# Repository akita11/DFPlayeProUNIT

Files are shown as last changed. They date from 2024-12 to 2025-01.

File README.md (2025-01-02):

# DFPlayerProUNIT

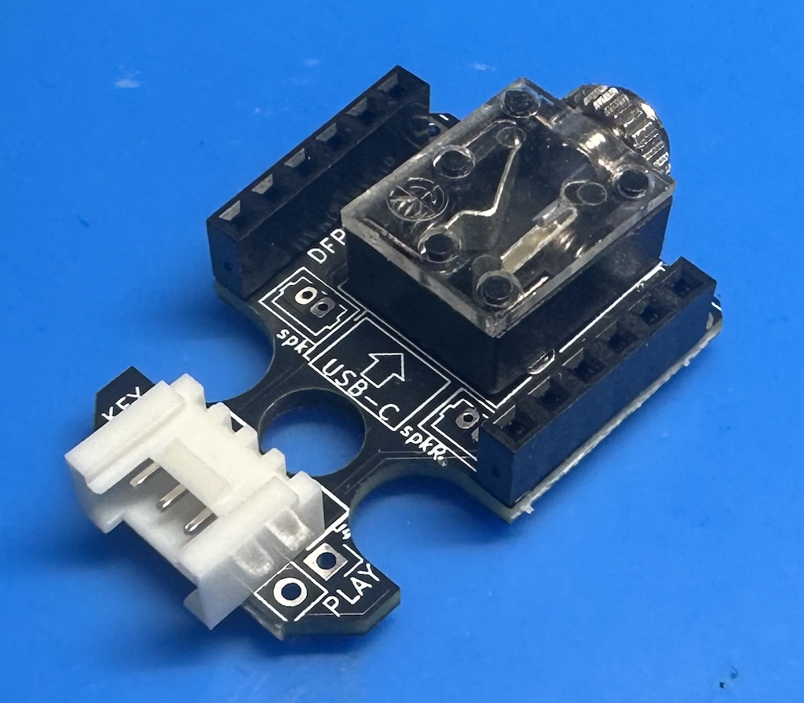
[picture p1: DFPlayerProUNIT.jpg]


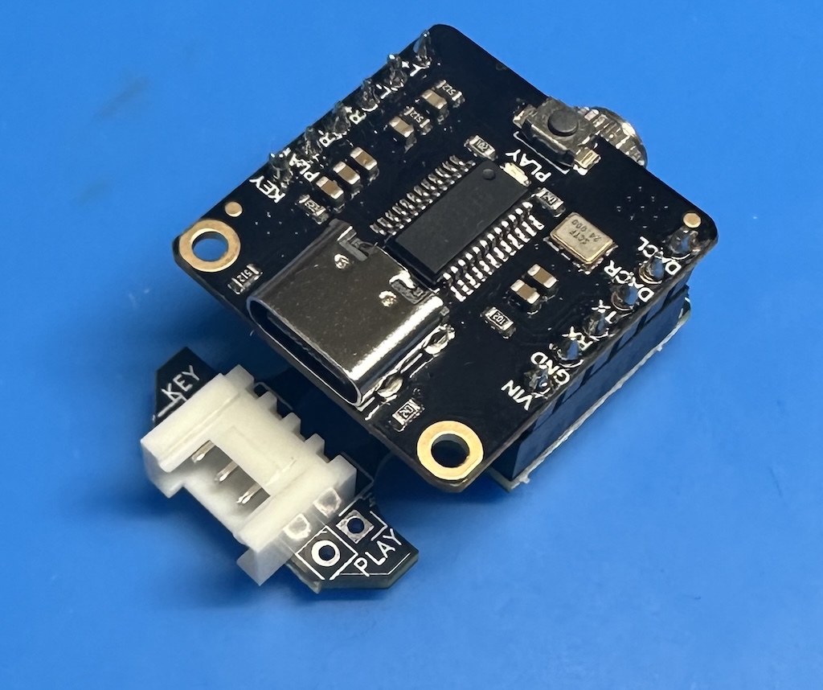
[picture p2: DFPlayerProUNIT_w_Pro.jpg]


DFRobotの音声プレーヤモジュール[DFPlayer Pro](https://www.switch-science.com/products/8005)をGrove端子を接続して制御できるモジュールです。Grove端子からシリアル(UART)通信で音声再生などを制御することができます。（UIFlow(v1)用のブロックも用意する予定）

※DFPlayerProは付属していません

## 使い方（接続方法）

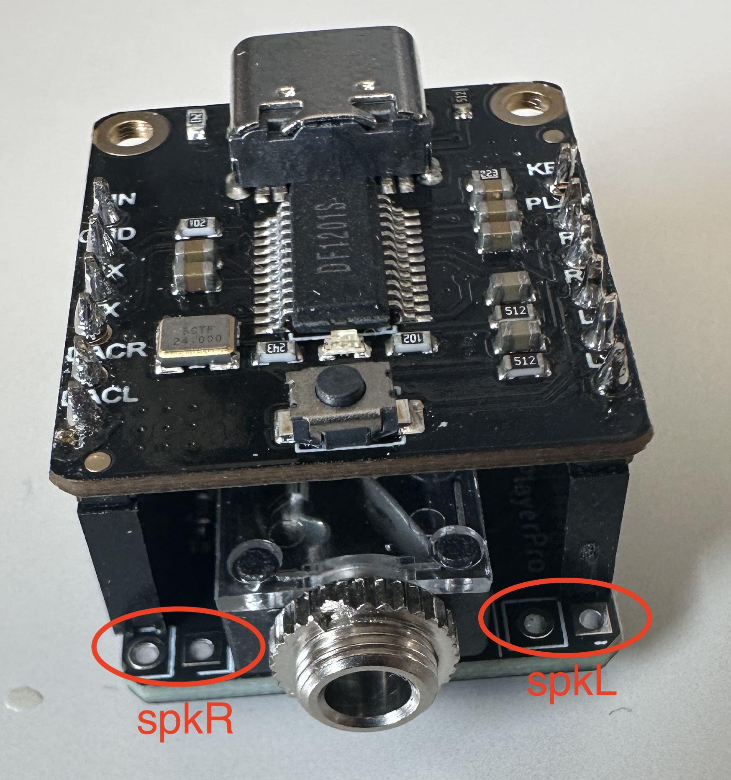
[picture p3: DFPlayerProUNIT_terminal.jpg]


以下のようにスピーカやアンプを接続し、Grove端子からの制御で音声を再生します。また基板上の"PAYE"と"KEY"のシルクが示されている2組の端子は、それぞれDFPlayerProのKEY、PLAY端子に接続されていますので、これらを使って再生を制御することもできます（詳細はDFPlayerProのマニュアルを参照してください）

### アンプ付きスピーカに接続する場合

3.5mmジャック（ステレオ：上部中央）に3.5mmステレオケーブル等でアンプに接続します。

### スピーカを直接接続する場合

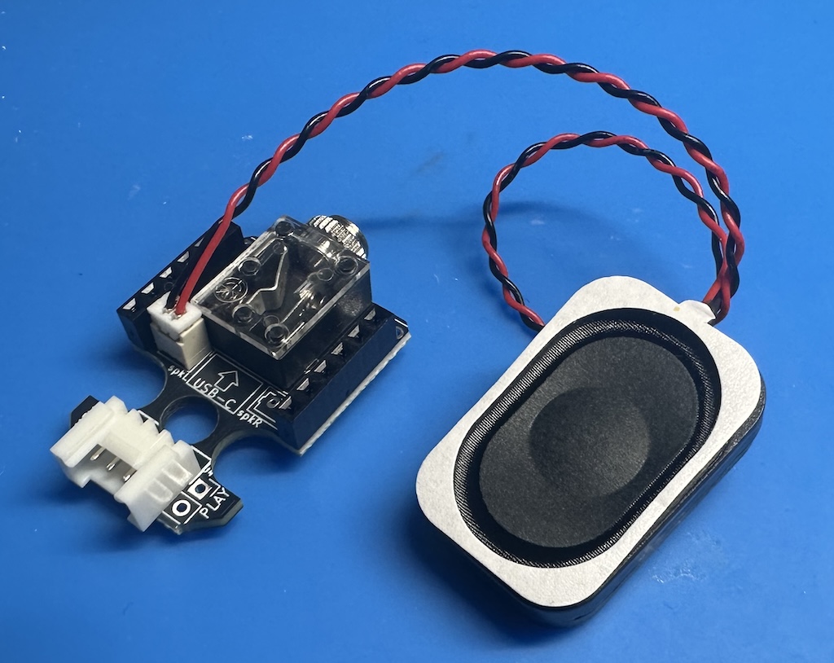
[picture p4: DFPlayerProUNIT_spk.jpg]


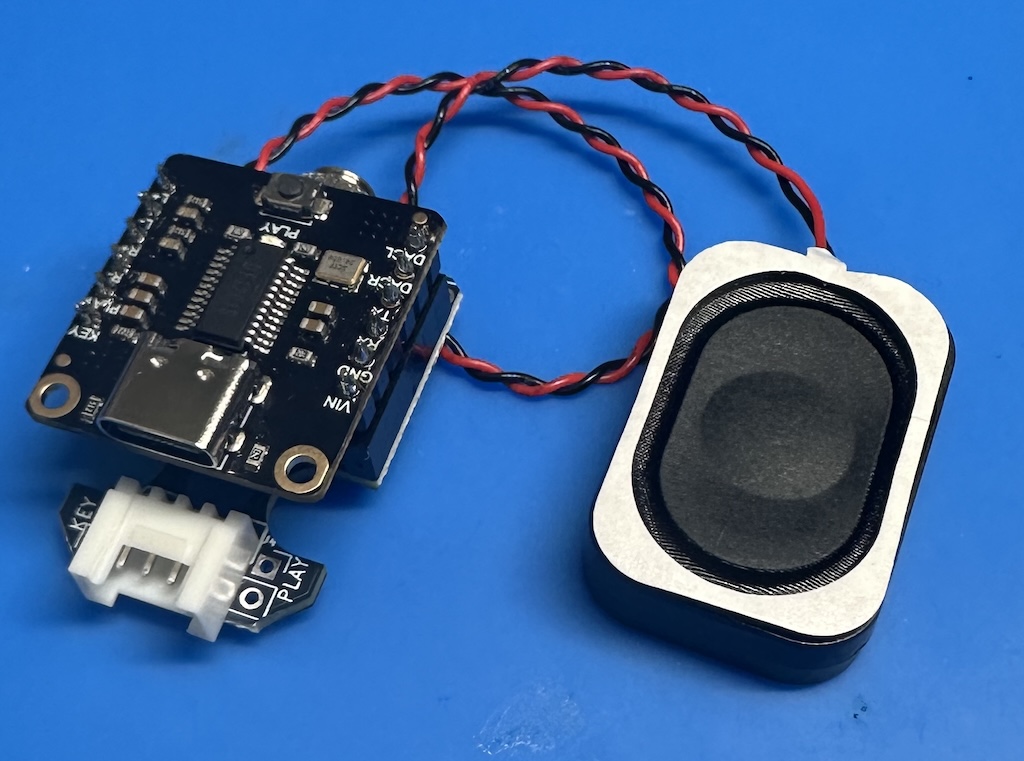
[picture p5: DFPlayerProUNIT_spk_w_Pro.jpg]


本体上部の2つの2.54mmた端子にスピーカを接続します。spkLとspkRがそれぞれお左と右のスピーカです。基板中央部に1.25mmピッチコネクタ(Molex 53047-0210用)をとりつける端子があり、市販の小型スピーカ（M5Stack本体に使われているものなど。AliExpressやTaobaoでも同等品があります）を接続することができます。

### 3.5mmジャックに直接スピーカを接続する方法

3.5mmジャックに直接スピーカを接続することもできます。その場合は、基板裏面のハンダジャンパを以下のように修正してください。

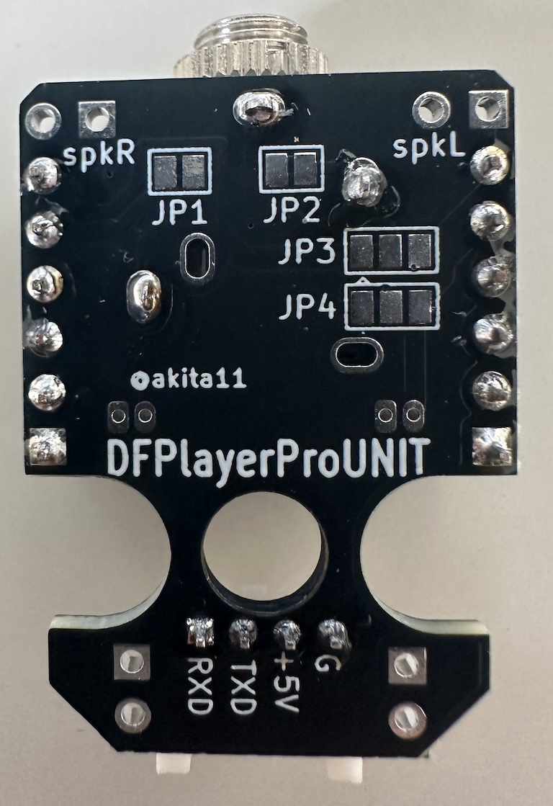
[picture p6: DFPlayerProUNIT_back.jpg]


- JP1をカット
- JP2・JP3の中央と△マーク側をカットし、中央と反対側（△マークがない側）をショート

## 使い方（ソフトウエア）

あらかじめ、DFPlayerProをUSB Type-Cケーブルを使ってPCへ接続し、現れるドライブに使用する音声データ（*.mp3等）をコピーしておきます。（このときコピーした順番が、再生時に使用する「曲番号」になります）

### UIFlow(v1)での使い方

「DFPlayerPro.m5b」をダウンロードし、UIFlow(v1)の"Custom"の"Open *.m5b"からこのファイルを指定すると、Init、Play、Volumeの3つのブロックを使用できます。

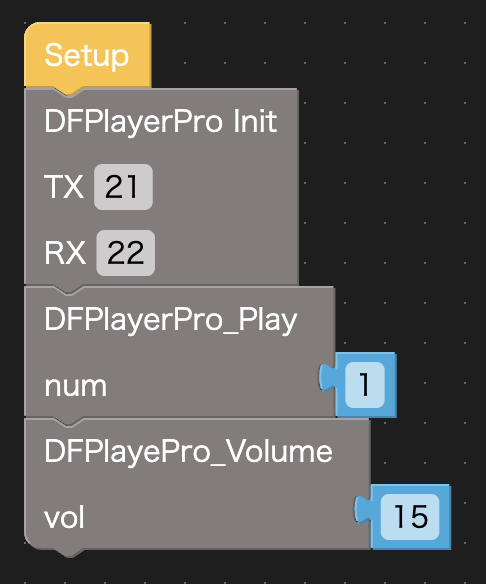
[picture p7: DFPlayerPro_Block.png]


- DFPlayerPro_Init : 初期化。最初に1回だけ読み出します。"TX"と"RX"には、使用するGroveポート・マイコン本体にあわせて、使用するピン番号を指定します。例えば、M5StackBasicのPortA（本体の赤いコネクタ）の場合は、上図のようにTX=21、RX=22を指定します。M5StackCore2のPortAの場合は、TX=32、RX=33となります。
- DFPlayerPro_Play : numに指定した「曲番号」の音声を再生します。
- DFPlayerPro_Volume : volに指定した音量に設定します。

### その他のソフトウエアでの使い方

Arduino用にはライブラリがあるようなので、そちらを使ってもOKです。
あるいは、DFPlayerProのデータシート等を参考に、制御コマンドを送信して使用してください。

## Author

Junichi Akita (@akita11) / akita@ifdl.jp

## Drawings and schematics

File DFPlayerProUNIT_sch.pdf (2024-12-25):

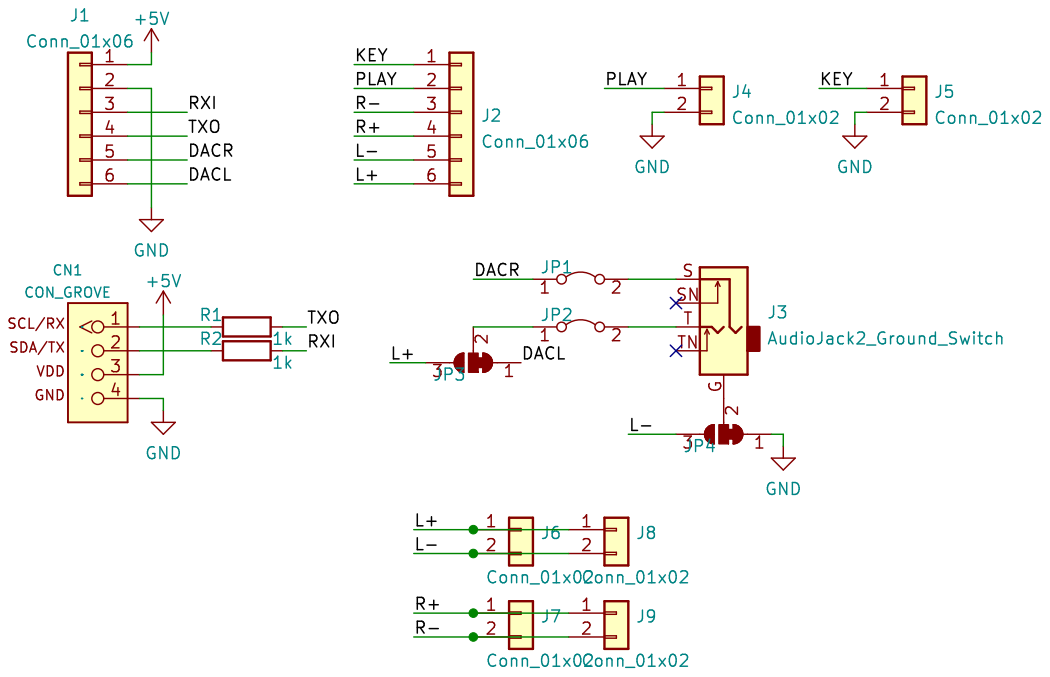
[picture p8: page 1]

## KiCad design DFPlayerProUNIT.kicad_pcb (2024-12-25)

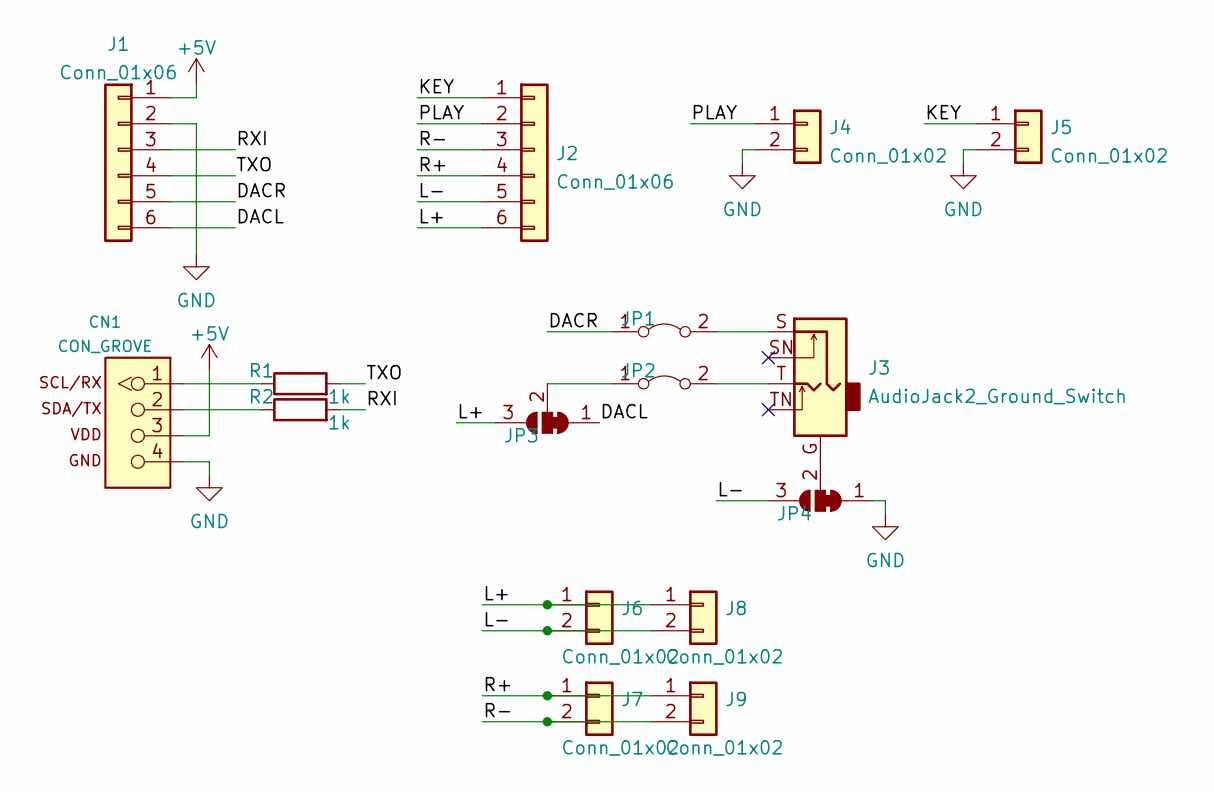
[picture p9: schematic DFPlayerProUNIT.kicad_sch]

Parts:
CN1: CON_GROVE; CON_GROVE_H
J1, J2: Conn_01x06; PinSocket_1x06_P2.54mm_Vertical
J3: AudioJack2_Ground_Switch; CON_AJ-1780
J4, J5, J6, J7: Conn_01x02; PinSocket_1x02_P2.54mm_Vertical
J8, J9: Conn_01x02; Molex_PicoBlade_53047-0210_1x02_P1.25mm_Vertical
JP1, JP2: Jumper_2_Bridged; SolderJumper-2_P1.3mm_Bridged2Bar_Pad1.0x1.5mm
JP3, JP4: SolderJumper_3_Bridged12; SolderJumper-3_P1.3mm_Bridged12_Pad1.0x1.5mm
R1, R2: 1k; R_0603_1608Metric

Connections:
+5V: CN1.3, J1.1
/DACL: J1.6, JP3.1 (A)
/DACR: J1.5, JP1.1 (A)
/KEY: J2.1, J5.1
/L+: J2.6, J6.1, J8.1, JP3.3 (B)
/L-: J2.5, J6.2, J8.2, JP4.3 (B)
/PLAY: J2.2, J4.1
/R+: J2.4, J7.1, J9.1
/R-: J2.3, J7.2, J9.2
/RXI: J1.3, R2.2
/TXO: J1.4, R1.2
GND: CN1.4, J1.2, J4.2, J5.2, JP4.1 (A)
unnamed: CN1.1, R1.1
unnamed: CN1.2, R2.1
unnamed: J3.S, JP1.2 (B)
unnamed: J3.T, JP2.2 (B)
unnamed: JP2.1 (A), JP3.2 (C)
unnamed: J3.G, JP4.2 (C)

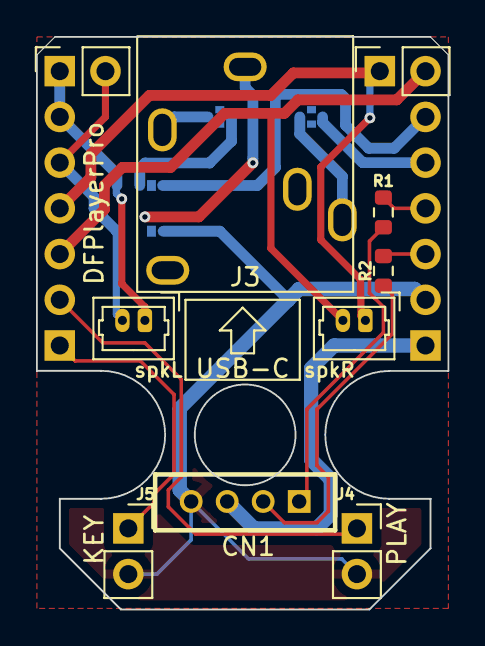
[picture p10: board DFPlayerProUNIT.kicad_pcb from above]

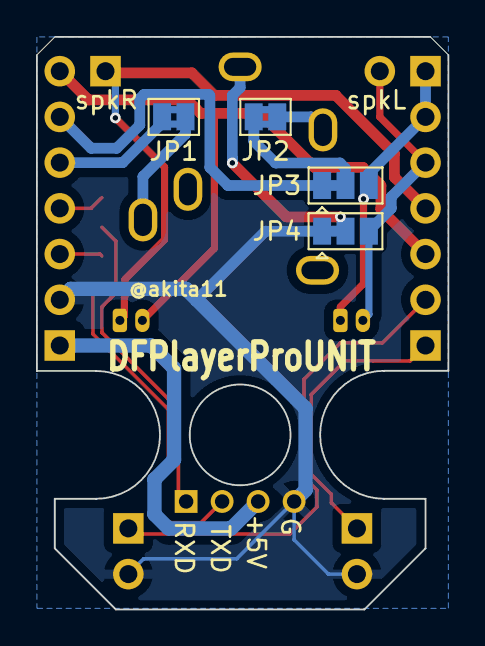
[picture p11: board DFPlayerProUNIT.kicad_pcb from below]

Board: 2 copper layers, 22.9 x 31.8 mm, 16 parts (4 on the bottom side), 18 nets.
